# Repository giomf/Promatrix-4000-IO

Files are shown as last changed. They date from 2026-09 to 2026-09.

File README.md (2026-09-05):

# Promatix-4000-IO

8-output / 7-input digital IO board (RP2040-based) with USB serial control.

* `PCB/` – KiCad hardware design.
* `firmware/` – Rust firmware (Embassy), see `firmware/README.md`.
* `protocol/` – wire protocol shared between firmware and `control`.
* `control/` – host-side Rust library + `promatrix` CLI, see `control/README.md`.

Enter the Nix dev shell (`nix develop`) for the pinned toolchain and tools
used by all three Rust crates.

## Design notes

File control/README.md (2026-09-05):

# control

Host-side Rust library + CLI (`promatrix`) for talking to a
Promatrix-4000-IO board over the USB CDC-ACM serial port its firmware
exposes: set outputs, request a status snapshot, and stream input-change
events. Speaks the wire protocol defined in `../protocol` — the same crate
the firmware itself uses, so the two can't drift apart.

## Prerequisites

Enter the Nix dev shell (`nix develop`, from the repo root) — it provides
the pinned Rust toolchain plus `pkg-config`/`udev`, which `serialport`'s
Linux backend needs to build.

## CLI

```sh
just run -- --port /dev/ttyACM0 set 3 on    # set Out3 high
just run -- --port /dev/ttyACM0 get         # print one STATUS snapshot
just run -- --port /dev/ttyACM0 watch       # snapshot, then stream EVT lines
```

(`just build`/`just build-release` build without running.) `--port` is
required; it can also be set once via the `PROMATRIX_PORT` env var instead
of passing `-p`/`--port` every time. The board's data interface is
typically `/dev/ttyACM0` and its log interface `/dev/ttyACM1` — see
`../firmware/README.md`.

`set` accepts `0`/`1`, `on`/`off`, or `true`/`false` for the value.

## Library

```rust
let mut client = control::Client::open("/dev/ttyACM0")?;
client.set_output(3, true)?;               // Out3 (1-indexed) on
let (outputs, inputs) = client.status()?;  // blocks for the STATUS reply
loop {
    match client.recv_event()? {
        control::Event::InputChanged { channel, value } => { /* channel is 0-indexed */ }
        control::Event::Status { outputs, inputs } => { /* bitmasks */ }
    }
}
```

`Client::open` starts a background thread that parses incoming lines and
delivers them as `Event`s through `recv_event`/`try_recv_event`; writes
(`set_output`/`get_status`/`status`) happen synchronously on the calling
thread. `status` sends `GetStatus` and blocks for the `Status` reply
specifically, discarding any unsolicited event (e.g. an `InputChanged`)
that happens to race ahead of it — use `get_status` + `recv_event`
directly if you want to see those too. Unrecognized lines from the device
(stray log output, anything the `protocol` crate's `parse_event` doesn't
understand) are silently dropped.

## Layout

* `src/lib.rs` – `Client`: opens the port, streams events off a background
  thread, sends commands.
* `src/main.rs` – `promatrix` CLI built on top of the library.
* `justfile` – build/run recipes.

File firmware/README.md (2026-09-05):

# Promatrix-4000-IO Firmware

Rust firmware for the RP2040 Zero (Waveshare), built on [Embassy](https://embassy.dev).

It controls 8 digital outputs (via a ULN2803A Darlington array) and senses 7
digital inputs (via PC817 optocouplers) in near real-time, and exposes both
to a host PC over a USB CDC-ACM ("virtual serial port") connection. A second
CDC-ACM interface carries plain-text logs.

## Prerequisites

Enter the Nix dev shell (`nix develop`) which provides the pinned Rust
toolchain (with the `thumbv6m-none-eabi` target), `picotool` and `just` for
flashing.

Flashing goes through the RP2040's built-in USB bootloader rather than a
debug probe. A board already running this firmware reboots itself into
BOOTSEL mode on request (see `src/reset.rs`), so `just flash`/`flash-release`
work as-is with no button-pressing. For a blank board, or one stuck in a
panic, hold the BOOT button while plugging in (or resetting) it so it
enumerates as `RP2 Boot`, then flash. If `picotool` reports a permissions
error, install its udev rule (`services.udev.packages = [ pkgs.picotool ];`
on NixOS) so your user can access the device without `sudo`.

## Build & flash

```sh
just flash          # debug build
just flash-release  # release build
```

(`just build`/`just build-release` build without flashing.) This runs
`picotool load -f -x -t elf ...` to flash the ELF and boot into it; see
`justfile`.

## Logs

The board must be in a normal, running state (not BOOTSEL) for logs to
appear. Logs are plain ASCII text on a second CDC-ACM serial port — no
special decoding needed:

```sh
just logs                  # defaults to /dev/ttyACM1
just logs /dev/ttyACM0     # override if the port numbering differs
```

See `src/log.rs` for the logging implementation and `src/usb.rs` for how the
two CDC-ACM interfaces are set up.

## Pin mapping

| Logical channel | GPIO | Notes |
|---|---|---|
| Out1..Out8 | 0..7 | direct, logical "on" == GPIO high |
| In1 | 10 | electrical low == input active |
| In2 | 9 | electrical low == input active |
| In3 | 8 | electrical low == input active |
| In4 | 14 | electrical low == input active |
| In5 | 13 | electrical low == input active |
| In6 | 12 | electrical low == input active |
| In7 | 11 | electrical low == input active |
| In8 | — | not wired on this board revision |

See `src/io.rs` for details on the output/input electrical polarity.

## USB protocol

The device enumerates as a USB CDC-ACM serial port (VID/PID
`16c0:27dd`, the pid.codes "Test PID" — replace with a real allocation before
shipping). Talk to it with any serial terminal/library using a simple,
line-based (`\n`-terminated) text protocol:

Host -> device:

```
SET <channel> <0|1>   set output <channel> (1..=8) to 0 or 1
GET                    request a full status snapshot
```

Device -> host:

```
EVT IN <channel> <0|1>            input <channel> (1..=7) changed, sent as soon as detected (debounced ~5ms)
STATUS OUT <8 bits> IN <7 bits>   full snapshot, sent in response to GET, MSB = highest channel
```

See `../protocol/src/lib.rs` for the exact grammar (a small `#![no_std]`
crate shared with the host control tool in `../control`, so the two can't
drift apart). `../control`'s `promatrix` CLI speaks it out of the box; see
`../control/README.md`.

## Layout

* `src/main.rs` – entry point, peripheral init and task spawning.
* `src/io.rs` – physical GPIO <-> logical channel mapping for outputs/inputs.
* `src/usb.rs` – USB CDC-ACM device/class setup (data + log interfaces).
* `src/log.rs` – plain-text logging over the second CDC-ACM interface.
* `src/reset.rs` – vendor USB interface letting `picotool -f` reboot the
  board into BOOTSEL mode without the BOOT button.
* `src/channels.rs` – inter-task queues (parsed commands, outgoing events).
* `src/state.rs` – shared atomic snapshot of current output/input state.
* `src/tasks.rs` – async tasks: USB reader/writer, output command handler,
  one input-watcher task per input pin.
* `memory.x` / `build.rs` – RP2040 linker memory layout.
* `.cargo/config.toml` – build target and `cargo run`'s `picotool` runner.

See also `../protocol` (shared wire protocol) and `../control` (host CLI
and library).
* `justfile` – build/flash/log recipes (see `just --list`).

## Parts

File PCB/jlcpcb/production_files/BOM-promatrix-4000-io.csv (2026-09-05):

Comment | Designator | Footprint | LCSC | Quantity
10kΩ | R10,R11,R12,R13,R14,R8,R9 | R_0402 | C25744 | 7
2.2kΩ | R1,R2,R3,R4,R5,R6,R7 | R_0402 | C25879 | 7
DC050-T | DC1 | DC-IN_DC050-T | C431534 | 1
JL127-50002G01 | CN1,CN2 | CONN-TH_2P-P5.08_JL127-50002G01 | C387826 | 2
PC817X3CSP9F | U1,U2,U3,U4,U5,U6,U7 | OPTO-SMD-4_L4.6-W6.5-P2.54-LS10.3-TL | C41807 | 7
R-RJ45R08P-A004 | RJ1,RJ2,RJ3,RJ4 | RJ45-TH_R-RJ45R08P-A004 | C385834 | 4
ULN2803A_C845537 | U9 | SOP-18_L11.4-W7.6-P1.27-LS10.6-BL | C845537 | 1
~ | U8 | rp2040-zero |  | 1

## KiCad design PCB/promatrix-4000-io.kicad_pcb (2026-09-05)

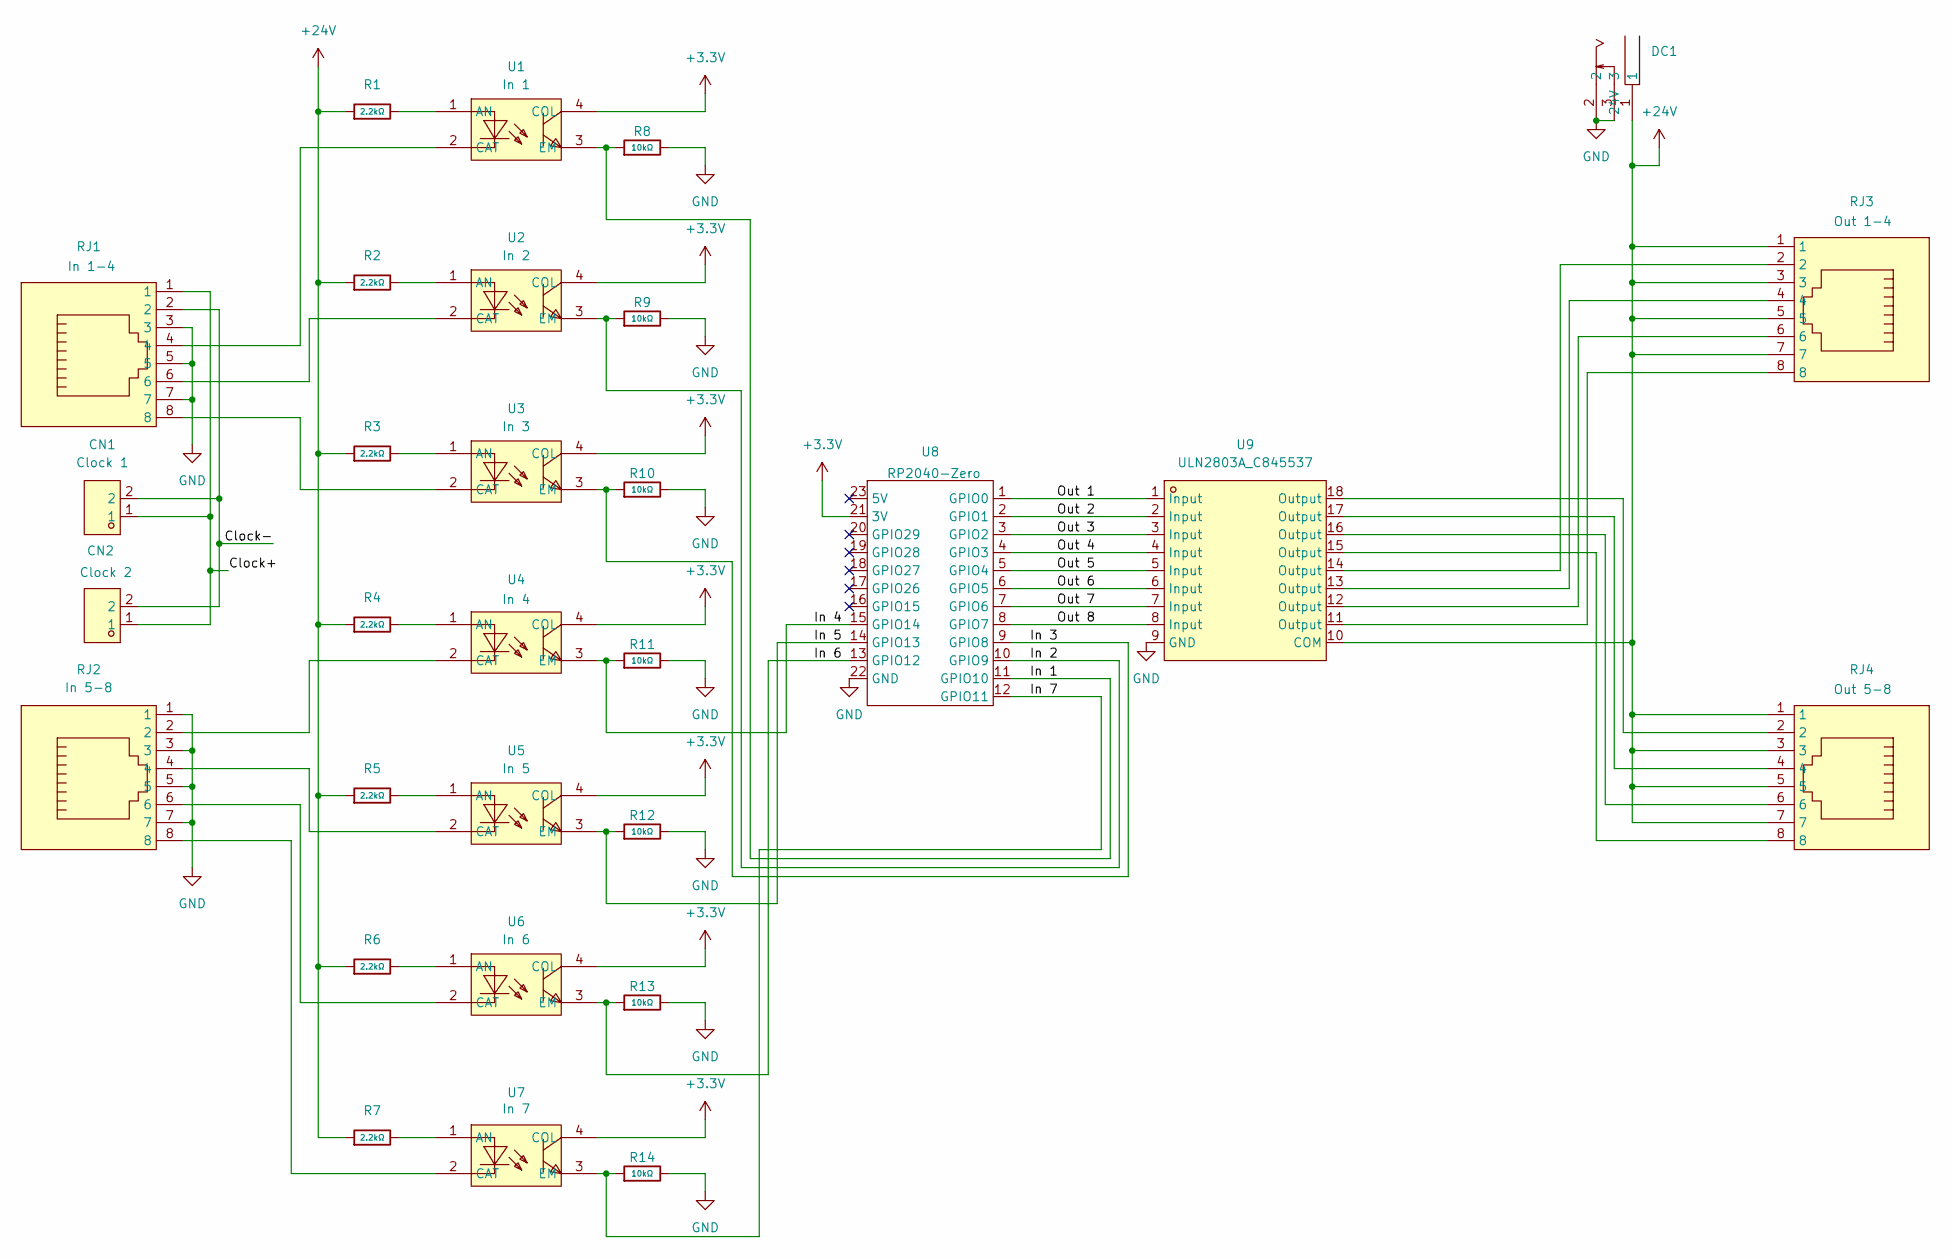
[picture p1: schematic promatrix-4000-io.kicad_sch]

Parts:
CN1, CN2: JL127-50002G01; CONN-TH_2P-P5.08_JL127-50002G01; MPN JL127-50002G01; LCSC Part C387826
DC1: DC050-T; DC-IN_DC050-T; LCSC Part C431534
R1, R2, R3, R4, R5, R6, R7: 2.2kΩ; R_0402; Overload Voltage (Max) 50V; Tolerance ±1%; Part 0402WGF2201TCE; LCSC C25879
R8, R9, R10, R11, R12, R13, R14: 10kΩ; R_0402; Overload Voltage (Max) 50V; Tolerance ±1%; Part 0402WGF1002TCE; LCSC C25744
RJ1, RJ2, RJ3, RJ4: R-RJ45R08P-A004; RJ45-TH_R-RJ45R08P-A004; MPN R-RJ45R08P-A004; LCSC Part C385834
U1, U2, U3, U4, U5, U6, U7: PC817X3CSP9F; OPTO-SMD-4_L4.6-W6.5-P2.54-LS10.3-TL; MPN PC817X3CSP9F; LCSC Part C41807
U8: rp2040-zero
U9: ULN2803A_C845537; SOP-18_L11.4-W7.6-P1.27-LS10.6-BL; MPN ULN2803A; LCSC Part C845537

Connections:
+3.3V: U1.4 (COL), U2.4 (COL), U3.4 (COL), U4.4 (COL), U5.4 (COL), U6.4 (COL), U7.4 (COL), U8.21 (3V)
+24V: DC1.1, R1.1, R2.1, R3.1, R4.1, R5.1, R6.1, R7.1, RJ3.1, RJ3.3, RJ3.5, RJ3.7, RJ4.1, RJ4.3, RJ4.5, RJ4.7, U9.10 (COM)
/Clock+: CN1.1, CN2.1, RJ1.1
/Clock-: CN1.2, CN2.2, RJ1.2
/In 1: R8.1, U1.3 (EM), U8.11 (GPIO10)
/In 2: R9.1, U2.3 (EM), U8.10 (GPIO9)
/In 3: R10.1, U3.3 (EM), U8.9 (GPIO8)
/In 4: R11.1, U4.3 (EM), U8.15 (GPIO14)
/In 5: R12.1, U5.3 (EM), U8.14 (GPIO13)
/In 6: R13.1, U6.3 (EM), U8.13 (GPIO12)
/In 7: R14.1, U7.3 (EM), U8.12 (GPIO11)
/Out 1: U8.1 (GPIO0), U9.1 (Input)
/Out 2: U8.2 (GPIO1), U9.2 (Input)
/Out 3: U8.3 (GPIO2), U9.3 (Input)
/Out 4: U8.4 (GPIO3), U9.4 (Input)
/Out 5: U8.5 (GPIO4), U9.5 (Input)
/Out 6: U8.6 (GPIO5), U9.6 (Input)
/Out 7: U8.7 (GPIO6), U9.7 (Input)
/Out 8: U8.8 (GPIO7), U9.8 (Input)
GND: DC1.2, DC1.3, R8.2, R9.2, R10.2, R11.2, R12.2, R13.2, R14.2, RJ1.3, RJ1.5, RJ1.7, RJ2.1, RJ2.3, RJ2.5, RJ2.7, U8.22 (GND), U9.9 (GND)
unnamed: RJ3.2, U9.14 (Output)
unnamed: RJ3.4, U9.13 (Output)
unnamed: RJ3.6, U9.12 (Output)
unnamed: RJ3.8, U9.11 (Output)
unnamed: RJ4.2, U9.18 (Output)
unnamed: RJ4.4, U9.17 (Output)
unnamed: RJ4.6, U9.16 (Output)
unnamed: RJ4.8, U9.15 (Output)
unnamed: R1.2, U1.1 (AN)
unnamed: RJ1.4, U1.2 (CAT)
unnamed: R2.2, U2.1 (AN)
unnamed: RJ1.6, U2.2 (CAT)
unnamed: R3.2, U3.1 (AN)
unnamed: RJ1.8, U3.2 (CAT)
unnamed: R4.2, U4.1 (AN)
unnamed: RJ2.2, U4.2 (CAT)
unnamed: R5.2, U5.1 (AN)
unnamed: RJ2.4, U5.2 (CAT)
unnamed: R6.2, U6.1 (AN)
unnamed: RJ2.6, U6.2 (CAT)
unnamed: R7.2, U7.1 (AN)
unnamed: RJ2.8, U7.2 (CAT)

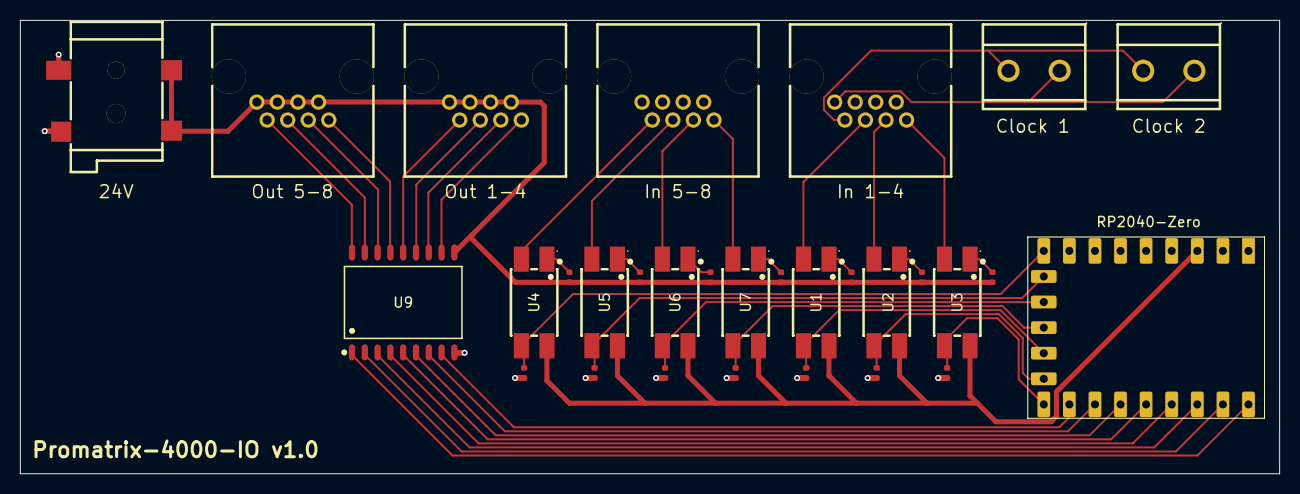
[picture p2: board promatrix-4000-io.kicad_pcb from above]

Board: 2 copper layers, 125.0 x 45.0 mm, 30 parts (0 on the bottom side), 42 nets.

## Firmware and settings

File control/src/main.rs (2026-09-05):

//! `promatrix` — command-line control tool for a Promatrix-4000-IO board.

use anyhow::{Context, Result};
use clap::{Parser, Subcommand};
use control::{Client, Event, NUM_INPUTS, NUM_OUTPUTS};

#[derive(Parser)]
#[command(about = "Talk to a Promatrix-4000-IO board over its USB serial port")]
struct Cli {
    /// Serial port the board's data interface is on, e.g. /dev/ttyACM0.
    #[arg(short, long, env = "PROMATRIX_PORT")]
    port: String,

    #[command(subcommand)]
    command: Cmd,
}

#[derive(Subcommand)]
enum Cmd {
    /// Set output <channel> (1..=8) to 0 or 1.
    Set {
        /// 1..=8
        channel: u8,
        /// 0/1, on/off, or true/false
        #[arg(value_parser = parse_bool, action = clap::ArgAction::Set)]
        value: bool,
    },
    /// Request and print a single status snapshot, then exit.
    Get,
    /// Print a status snapshot, then stream input-change events until
    /// interrupted (Ctrl-C).
    Watch,
}

fn parse_bool(s: &str) -> Result<bool, String> {
    match s.to_ascii_lowercase().as_str() {
        "1" | "on" | "true" => Ok(true),
        "0" | "off" | "false" => Ok(false),
        _ => Err(format!("expected 0/1/on/off, got {s:?}")),
    }
}

fn main() -> Result<()> {
    let cli = Cli::parse();
    let mut client = Client::open(&cli.port).with_context(|| format!("opening {}", cli.port))?;

    match cli.command {
        Cmd::Set { channel, value } => client.set_output(channel, value)?,
        Cmd::Get => print_status(client.status()?),
        Cmd::Watch => {
            print_status(client.status()?);
            loop {
                print_event(client.recv_event()?);
            }
        }
    }
    Ok(())
}

fn print_event(event: Event) {
    match event {
        Event::InputChanged { channel, value } => {
            println!("In{}  {}", channel + 1, if value { "on" } else { "off" });
        }
        Event::Status { outputs, inputs } => print_status((outputs, inputs)),
    }
}

fn print_status((outputs, inputs): (u8, u8)) {
    println!("Outputs:");
    print_channels("Out", outputs, NUM_OUTPUTS);
    println!("Inputs:");
    print_channels("In", inputs, NUM_INPUTS);
}

/// Print one `  <prefix><channel>  on|off` line per channel (1-indexed),
/// `<channel>` counting up from the least-significant bit of `value`.
fn print_channels(prefix: &str, value: u8, count: usize) {
    for ch in 1..=count {
        let label = format!("{prefix}{ch}");
        let state = if (value >> (ch - 1)) & 1 == 1 { "on" } else { "off" };
        println!("  {label:<5}{state}");
    }
}

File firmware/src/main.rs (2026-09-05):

//! Promatrix-4000-IO firmware.
//!
//! Targets the Waveshare RP2040-Zero board. Controls 8 digital outputs
//! (through a ULN2803A Darlington array) and senses 7 digital inputs
//! (through PC817 optocouplers) in near real-time, exposing both over a USB
//! CDC-ACM ("virtual serial port") connection to a host PC. See
//! [`protocol`] for the wire format and [`io`] for the physical pin mapping.

#![no_std]
#![no_main]

mod channels;
mod io;
mod log;
mod reset;
mod state;
mod tasks;
mod usb;

use embassy_executor::Spawner;
use panic_halt as _;

use crate::io::{InputPins, Inputs, OutputPins, Outputs};
use crate::usb::Usb;

#[embassy_executor::main(executor = "embassy_rp::executor::Executor", entry = "cortex_m_rt::entry")]
async fn main(spawner: Spawner) {
    let p = embassy_rp::init(Default::default());
    crate::log_info!("Promatrix-4000-IO firmware starting");

    let outputs = Outputs::new(OutputPins {
        out1: p.PIN_0,
        out2: p.PIN_1,
        out3: p.PIN_2,
        out4: p.PIN_3,
        out5: p.PIN_4,
        out6: p.PIN_5,
        out7: p.PIN_6,
        out8: p.PIN_7,
    });

    let Inputs(input_pins) = Inputs::new(InputPins {
        in1: p.PIN_10,
        in2: p.PIN_9,
        in3: p.PIN_8,
        in4: p.PIN_14,
        in5: p.PIN_13,
        in6: p.PIN_12,
        in7: p.PIN_11,
    });

    let Usb { device, sender, receiver, log_sender } = usb::init(p.USB, p.FLASH);

    spawner.spawn(usb::usb_task(device).unwrap());
    spawner.spawn(log::log_task(log_sender).unwrap());
    spawner.spawn(tasks::usb_reader_task(receiver).unwrap());
    spawner.spawn(tasks::usb_writer_task(sender).unwrap());
    spawner.spawn(tasks::output_task(outputs).unwrap());

    for (channel, pin) in input_pins.into_iter().enumerate() {
        spawner.spawn(tasks::input_task(pin, channel as u8).unwrap());
    }
}

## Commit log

2026-09-05 Add PCB
    [BOM-promatrix-4000-io.csv, freerouting.dsn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]
2026-11-04 fix: off by one error for inputs, on/off inverted, output 1-4 to 5-8 switch
